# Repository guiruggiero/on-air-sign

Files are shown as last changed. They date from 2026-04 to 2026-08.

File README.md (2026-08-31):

# On Air sign

Automated "On Air" sign using a Raspberry Pi Pico 2 W — shows your meeting and webcam status:
- No meeting → OFF ⚫
- Meeting, camera off → YELLOW 🟡
- Meeting, camera on → RED 🔴

Works with Zoom, Google Meet, Slack Huddle, Amazon Chime, and Microsoft Teams. Only activates when connected to your home WiFi.

## Setup

### Pico
Wire the WS2812 NeoPixel ring data line to **GP4**.

Print and assemble the enclosures from `enclosures/` — a snap-fit box for the NeoPixel ring and a case for the Pico 2 W. See [`enclosures/README.md`](enclosures/README.md) for print settings.

The Pico firmware comes in two implementations — pick the one matching your host monitor (see below).

#### Pico (push variant, pairs with the Windows host monitor)
Upload `pico-push/main.py` and `pico-push/dashboard.html` to the Pico 2 W using Thonny. Create `pico-push/secrets.py` on the device:
```python
SSID = "<wifi_name>"
PASSWORD = "<wifi_password>"
WEBREPL_PW = "<webrepl_password>"
```
Assign the Pico a static IP via a DHCP reservation on your router so the hardcoded IP in `host-win/monitor.js` never changes. The Pico runs a local HTTP server and the host pushes state to it directly, so both must be on the same LAN.

Optionally, upload `pico-push/onairsign.html` to your personal website for easy access to the dashboard without remembering the IP.

#### Pico (pull variant, pairs with the macOS host monitor)
Upload `pico-pull/main.py` to the Pico 2 W using Thonny. Create a feed named `on-air-sign` on [Adafruit IO](https://io.adafruit.com), then create `pico-pull/secrets.py` on the device:
```python
SSID = "<wifi_name>"
PASSWORD = "<wifi_password>"
WEBREPL_PW = "<webrepl_password>"
AIO_USERNAME = "<adafruit_io_username>"
AIO_KEY = "<adafruit_io_key>"
```
The Pico polls this feed over HTTPS and drives the sign from its value (`off`/`yellow`/`red`) — no LAN adjacency with the host required, and no inbound connections accepted. `host-mac` writing to the feed automatically is still in progress (see [host-mac/CLAUDE.md](host-mac/CLAUDE.md)); until then you can set the feed's value manually from the Adafruit IO dashboard to test the Pico side.

### Host monitor (Windows)
Requires Node.js and PowerShell 7 (`pwsh`). Set the HOME_SSID environment variable:
```powershell
[System.Environment]::SetEnvironmentVariable("HOME_SSID", "<your_ssid>", "User")
```
Then run:
```powershell
node host-win/monitor.js
```

#### Autostart
To run the monitor automatically on login via Windows Task Scheduler:
1. Copy `host-win/launch-monitor.vbs.example` → `host-win/launch-monitor.vbs` and fill in your Node.js path and repo path
2. Copy `host-win/On Air sign monitor.xml.example` → `host-win/On Air sign monitor.xml` and replace `DOMAIN\username`, `DATE`, and the paths in `<Actions>`
3. Open Task Scheduler → Action → Import Task, and select `host-win\On Air sign monitor.xml`

### Host monitor (macOS)
Requires Node.js and the Xcode Command Line Tools (for `swiftc` — usually already installed). Build the native probe once, then run:
```bash
cd host-mac
./build.sh
export HOME_SSID="<your_ssid>"
node monitor.js
```
On first run, grant these in System Settings → Privacy & Security: **Screen Recording** (so the probe can read meeting-app window titles — without it no meeting is detected) and **Location Services** for your terminal/Node (required by macOS to read the WiFi network name). Camera state needs no permission. See [host-mac/CLAUDE.md](host-mac/CLAUDE.md) for details.

#### Autostart
To run the monitor automatically on login via launchd:
1. Copy `host-mac/com.onairsign.monitor.plist.example` → `host-mac/com.onairsign.monitor.plist` and fill in your Node.js path, repo path, and HOME_SSID
2. Symlink or copy it into `~/Library/LaunchAgents/` and load it:
   ```bash
   cp "host-mac/com.onairsign.monitor.plist" ~/Library/LaunchAgents/
   launchctl load ~/Library/LaunchAgents/com.onairsign.monitor.plist
   ```

---

#### 📄 License
This project is licensed under the [MIT License](LICENSE). Attribution is required.

#### ⚠️ Disclaimer
This software is provided "as is" without any warranties. Use at your own risk. The author is not responsible for any consequences of using this software.

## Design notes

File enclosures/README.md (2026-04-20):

# Enclosures

3D print files for the project. No supports needed in any of the files.

For the most up-to-date designs, see Tinkercad profile [TinkerGui](https://www.tinkercad.com/users/7svhW7zioAZ).

## Pico case

Files: `Raspberry Pi Pico 2 W case - bottom.stl`, `Raspberry Pi Pico 2 W case - top.stl`

Based on maximilliampere's [slim modular Pico case](https://www.printables.com/model/61680-slim-modular-raspberry-pi-pico-case).

Print settings:
- Layer height: 0.2 mm
- Infill: 20%

## Sign box

Files: `On Air box - base.stl`, `On Air box - lid.stl`, `On Air box - letters.stl`

Houses the 12-LED WS2812 NeoPixel ring. Custom designs.

Print settings (base):
- Layer height: 0.2 mm
- Infill: 15%

Print settings (lid and letters):
- Layer height: 0.3 mm
- Infill: 15%

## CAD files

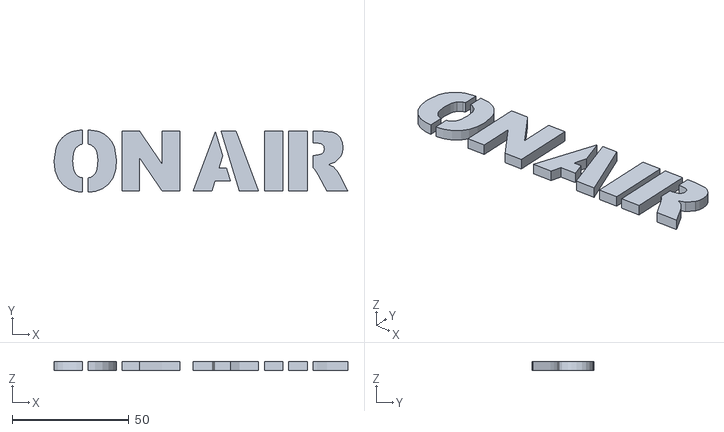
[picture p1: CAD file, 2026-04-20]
enclosures/On Air box - letters.stl
125.9 x 26.7 x 4.00

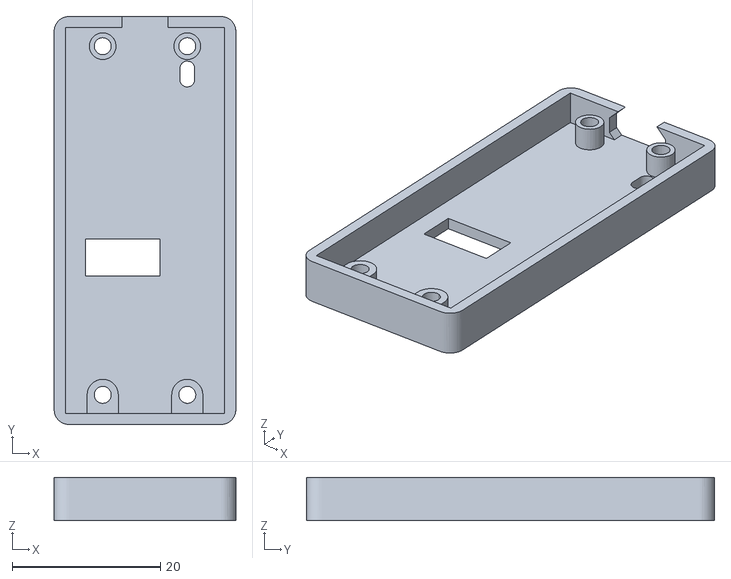
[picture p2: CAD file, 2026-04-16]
enclosures/Raspberry Pi Pico 2 W case - top.stl
24.5 x 55.0 x 5.80

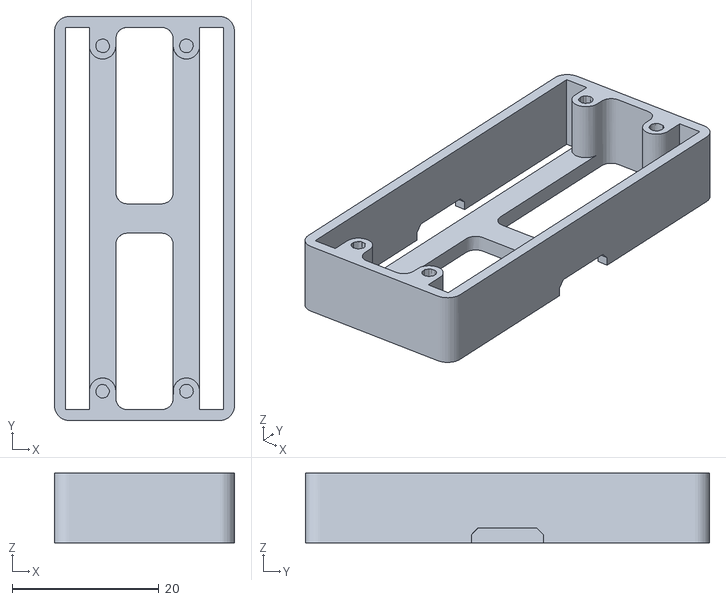
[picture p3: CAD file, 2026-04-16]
enclosures/Raspberry Pi Pico 2 W case - bottom.stl
24.5 x 55.0 x 9.50

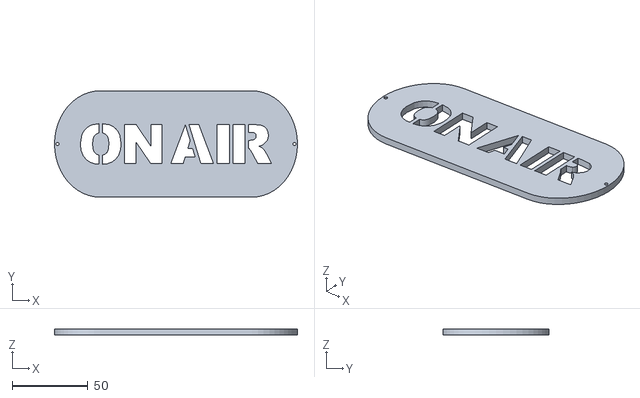
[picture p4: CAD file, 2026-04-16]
enclosures/On Air box - lid.stl
160.0 x 70.0 x 4.00

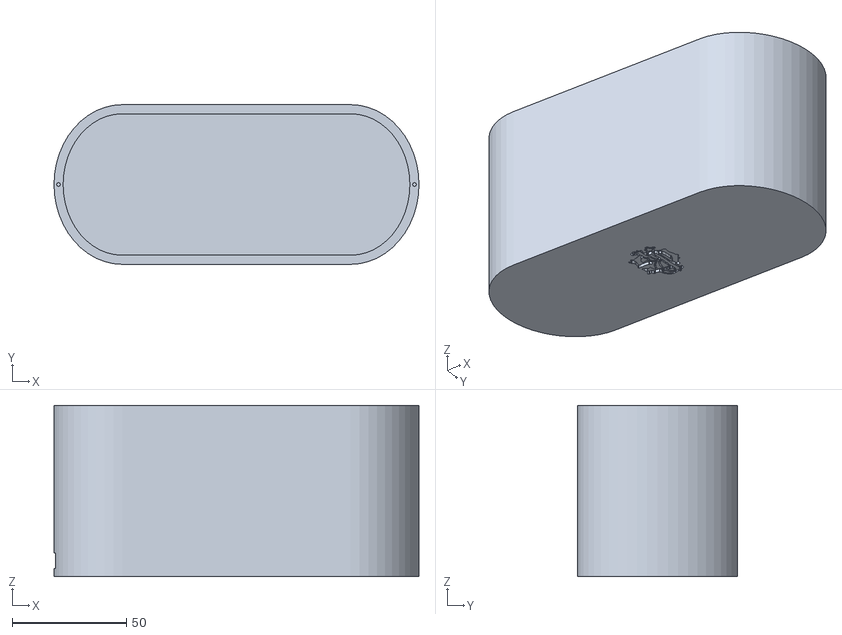
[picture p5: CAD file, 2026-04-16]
enclosures/On Air box - base.stl
160.0 x 70.0 x 75.0

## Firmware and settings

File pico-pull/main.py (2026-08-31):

# Imports
import secrets
import time
import os
import rp2
import machine
import array
import network
import socket
import ssl
import json
import gc

# Initializations
SSID = secrets.SSID
PASSWORD = secrets.PASSWORD
WEBREPL_PW = secrets.WEBREPL_PW
AIO_USERNAME = secrets.AIO_USERNAME
AIO_KEY = secrets.AIO_KEY

# Adafruit IO feed ("red", "yellow", or "off")
AIO_HOST = "io.adafruit.com"
AIO_FEED = "on-air-sign"
AIO_PATH = f"/api/v2/{AIO_USERNAME}/feeds/{AIO_FEED}/data/last"
POLL_INTERVAL_MS = 3_000 # 3s
WATCHDOG_TIMEOUT_MS = 300_000 # 5m; turn off if feed unreachable or stale info
UNIX_EPOCH_OFFSET = 946_684_800 # seconds between Adafruit IO's created_epoch and MicroPython's time.time() epoch

# Persistent logging to flash
LOG_PATH = "logs.log"
ERR_PATH = "errors.log"
LOG_MAX_BYTES = 20_000

def trim_log(path):
    try:
        size = os.stat(path)[6]
        if size > LOG_MAX_BYTES:
            with open(path, "r") as f:
                f.seek(size // 2)
                f.readline() # Discard the partial line at the seek point
                keep = f.read()
            with open(path, "w") as f:
                f.write(keep)
    except OSError:
        pass

def log(msg):
    t = time.localtime(time.time() - 8 * 3600)
    line = f"[{t[1]:02}-{t[2]:02} {t[3]:02}:{t[4]:02}:{t[5]:02}] {msg}"
    print(line)
    try:
        trim_log(LOG_PATH)
        with open(LOG_PATH, "a") as f:
            f.write(line + "\n")
    except Exception:
        pass
    return line

def log_error(msg):
    line = log(msg)
    try:
        trim_log(ERR_PATH)
        with open(ERR_PATH, "a") as f:
            f.write(line + "\n")
    except Exception:
        pass

# GRB values (brightness-adjusted, GRB byte order for WS2812)
BRIGHTNESS = 0.4  # 0.0 (off) to 1.0 (full brightness)
def _to_grb(r, g, b):
    return (int(g * BRIGHTNESS) << 16) | (int(r * BRIGHTNESS) << 8) | int(b * BRIGHTNESS)
GRB_OFF    = _to_grb(0, 0, 0)
GRB_YELLOW = _to_grb(204, 153, 0)
GRB_RED    = _to_grb(255, 0, 0)
GRB_GREEN  = _to_grb(0, 255, 0)

STATE_MAP = {
    "off": GRB_OFF,
    "o": GRB_OFF,
    "yellow": GRB_YELLOW,
    "y": GRB_YELLOW,
    "red": GRB_RED,
    "r": GRB_RED,
}

# PIO NeoPixel driver for Raspberry Pi Pico 2
@rp2.asm_pio(sideset_init = rp2.PIO.OUT_LOW, out_shiftdir = rp2.PIO.SHIFT_LEFT, autopull = True, pull_thresh = 24)
def ws2812():
    T1, T2, T3 = 2, 5, 3
    wrap_target()
    label("bitloop")
    out(x, 1).side(0)[T3 - 1]
    jmp(not_x, "do_zero").side(1)[T1 - 1]
    jmp("bitloop").side(1)[T2 - 1]
    label("do_zero")
    nop().side(0)[T2 - 1]
    wrap()

# Initialize StateMachine on the data pin
DATA_PIN = 4
NUM_LEDS = 12
sm = rp2.StateMachine(0, ws2812, freq = 8_000_000, sideset_base = machine.Pin(DATA_PIN))
sm.active(1)
pixel_data = array.array("I", [0] * NUM_LEDS) # Internal buffer

# Change color of LEDs
def set_sign(grb):
    for i in range(NUM_LEDS):
        pixel_data[i] = grb
    sm.put(pixel_data, 8) # Send to PIO
    time.sleep_ms(10) # Brief settle time to ensure the PIO FIFO buffer is cleared

# Sync local clock to NTP time
def sync_ntp():
    try:
        import ntptime
        ntptime.settime()
        log("NTP time synced")
    except Exception:
        log_error("NTP sync failed")

# Connect to WiFi
wlan = network.WLAN(network.STA_IF)
def connect_wifi(initial=False):
    wlan.active(True)
    if not wlan.isconnected():
        wlan.connect(SSID, PASSWORD)
        log("Connecting to WiFi...")
        on = False
        for _ in range(40): # 20s timeout
            if wlan.isconnected():
                break
            on = not on
            set_sign(GRB_GREEN if on else GRB_OFF) # Blink green while connecting
            time.sleep(0.5)
        else:
            set_sign(GRB_OFF)
            log_error("WiFi connection failed, resetting...")
            machine.reset()

    ip = wlan.ifconfig()[0]
    log(f"Connected! IP: {ip}")
    sync_ntp()
    if initial:
        set_sign(GRB_GREEN) # Solid green on first boot
        time.sleep(3)
        set_sign(GRB_OFF)
    return ip

ip = connect_wifi(initial=True)

# WebREPL for updating files over WiFi
try:
    import webrepl
    webrepl.start(password = WEBREPL_PW) # Update via WiFi on http://micropython.org/webrepl with ws://<PICO_IP>:8266
except Exception:
    log_error("WebREPL not available")

# Dechunk an HTTP/1.1 chunked-transfer-encoded body
def dechunk(data):
    out = b""
    while data:
        size_end = data.index(b"\r\n")
        size = int(data[:size_end], 16)
        if size == 0:
            break
        chunk_start = size_end + 2
        out += data[chunk_start:chunk_start + size]
        data = data[chunk_start + size + 2:] # Skip the chunk's trailing \r\n
    return out

# Minimal HTTPS GET; reads until the server closes the connection
def https_get(host, path, headers):
    addr = socket.getaddrinfo(host, 443)[0][-1]
    raw = socket.socket()
    raw.settimeout(8.0)
    raw.connect(addr)
    s = ssl.wrap_socket(raw, server_hostname=host)
    try:
        req_lines = [f"GET {path} HTTP/1.1", f"Host: {host}", "Connection: close"]
        for k, v in headers.items():
            req_lines.append(f"{k}: {v}")
        req_lines.append("\r\n")
        s.write("\r\n".join(req_lines).encode())

        data = b""
        while True:
            chunk = s.read(1024)
            if not chunk:
                break
            data += chunk
    finally:
        s.close()

    header_end = data.index(b"\r\n\r\n")
    header_text = data[:header_end].decode()
    body = data[header_end + 4:]

    status_code = int(header_text.split("\r\n", 1)[0].split(" ")[1])
    resp_headers = {}
    for line in header_text.split("\r\n")[1:]:
        if ":" in line:
            k, v = line.split(":", 1)
            resp_headers[k.strip().lower()] = v.strip()

    if resp_headers.get("transfer-encoding") == "chunked":
        body = dechunk(body)

    return status_code, body

# Fetch current state and last update time from Adafruit IO
def fetch_state():
    status, body = https_get(AIO_HOST, AIO_PATH, {"X-AIO-Key": AIO_KEY})
    if status != 200:
        raise Exception(f"Adafruit IO returned HTTP {status}")
    data = json.loads(body)
    return data["value"], int(data["created_epoch"])

log(f"Polling Adafruit IO every {POLL_INTERVAL_MS // 1000}s")
last_fresh_time = time.ticks_ms()
last_ntp_sync = time.ticks_ms()
NTP_SYNC_INTERVAL = 24 * 60 * 60 * 1000 # 24 hours
STALE_MSG_LOGGED = False

while True:
    gc.collect() # Periodically clean up memory

    # Periodic NTP re-sync to correct clock drift
    if time.ticks_diff(time.ticks_ms(), last_ntp_sync) > NTP_SYNC_INTERVAL:
        sync_ntp()
        last_ntp_sync = time.ticks_ms()

    try:
        if not wlan.isconnected():
            log_error("WiFi lost, reconnecting...")
            connect_wifi()

        value, created_epoch = fetch_state()
        age_s = (time.time() + UNIX_EPOCH_OFFSET) - created_epoch

        if age_s <= WATCHDOG_TIMEOUT_MS // 1000:
            last_fresh_time = time.ticks_ms()
            STALE_MSG_LOGGED = False

            grb = STATE_MAP.get(value)
            if grb is None:
                log_error(f"Unknown feed value: {value}")
            elif grb != pixel_data[0]:
                log(f"State changed: {value}")
                set_sign(grb)
        elif not STALE_MSG_LOGGED:
            log(f"Feed value is stale ({age_s}s old), ignoring until it updates")
            STALE_MSG_LOGGED = True

    except Exception as e:
        log_error(f"Poll failed: {e}")

    # Watchdog: turn off sign if feed unreachable or stale info
    if pixel_data[0] != GRB_OFF and time.ticks_diff(time.ticks_ms(), last_fresh_time) > WATCHDOG_TIMEOUT_MS:
        log("No fresh feed value in 5 minutes, turning off sign")
        set_sign(GRB_OFF)

    time.sleep_ms(POLL_INTERVAL_MS)

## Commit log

2026-03-16 Added main from Claude with Gemini modifications and official example from Raspberry Pi
2026-03-16 Increased resiliency to network hiccups and memory issues
    [main.py]
2026-03-16 Improved stability and memory optimizations for long-running server
    [main.py]
2026-03-16 Updated camera check with multiple paths
2026-03-17 Simplified meeting check powershell command, improved timeouts, added graceful shutdown and heartbeat
2026-03-17 Changed PowerShell commands to encoded Base64 strings
2026-03-17 Enhanced PowerShell commands for silent execution
2026-03-17 Moved to PowerShell 7 for speed
2026-03-28 Added local manual control from any device, updates over WiFi with WebREPL
2026-03-28 Fixed webpage and serving it correctly
    [main.py]
2026-03-28 Fixed stale socket after WiFi reconnect
    [main.py]
2026-03-28 Guarded WebREPL import/start so missing setup doesn't crash on boot
    [main.py]
2026-03-28 Guarded mDNS setup so unsupported firmware doesn't crash on boot
    [main.py]
2026-03-28 Added 20s timeout to WiFi connection, reset Pico on failure
    [main.py]
2026-03-28 Removed local manual control from any device
2026-03-30 Refactor main.py: consolidate routes, precompute GRB colors, fix bare excepts, drop neopixel_ring.py
    [main.py]
2026-04-01 Organize repo into pico/ and host/ folders
2026-04-01 Feat: add resilience with Pico watchdog timeout, monitor heartbeat, socket recovery
2026-04-01 Extract inline PowerShell to dedicated script loaded from file
2026-04-02 Feat: persistent file logging with auto-rotation to both Pico and monitor, AGENTS.md hardlink to CLAUDE.md
2026-04-03 Fix: log trimming and timestamps include date, CORS headers on all responses, dashboard uses onairsign.local with error feedback, mDNS malformed packet guard
    [main.py]
2026-04-03 Improve resource usage and fix minor bugs across Pico and host
    [main.py]
2026-04-04 Fix: mDNS EADDRINUSE on re-run by closing existing socket before rebin
2026-04-07 Add Pico memory and uptime stats to dashboard
2026-04-07 Refactor: Pico logging to match host
2026-04-07 Hardcode Pico IP, remove env var and dashboard prompt
2026-04-07 Add /logs and /errors endpoints to Pico and link them in dashboard
    [main.py]
2026-04-08 Address SonarQube concerns
2026-04-16 Add 3D printing enclosure designs
    [On Air box - bottom.stl, On Air box - top.stl, Raspberry Pi Pico 2 W case - bottom.stl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]
2026-04-16 Add enclosures folder README
2026-04-20 Change file names, add letters and print settings
    [On Air box - base.stl, On Air box - letters.stl, On Air box - lid.stl]
2026-08-07 Docs: add SonarQube Cloud project key
2026-08-31 Fix: use node: import prefixes, [[ ]] in poll.sh, remove duplicate <html> tag, fix dead f-string, and improve RED button contrast
    [main.py]
2026-09-14 Docs: note admin dashboard integration pending on Pico firmware work
2026-10-10 Fix: raise RuntimeError instead of generic Exception in pico-pull
2026-11-02 Refact: reorganize repo into win/{host,pico} and mac/{host,pico}
2026-11-02 Refact: simplify mac host with router-MAC home check, native probe checks, and per-app meeting rules
2026-11-02 Refact: drop alive log, shorten probe timeout to 2s, and strip trailing newlines
2026-11-02 Feat: Pico receives the feed over MQTT; Mac polls every 3s
2026-11-02 Feat: Pico heartbeat to the pico feed and manual hold (red:60)
2026-11-02 Feat: Pico heartbeat reports used memory
2026-11-02 Fix: SonarQube findings in mac host monitor (complexity, unawaited promises, log injection)
2026-11-02 Docs: admin card live, buttons left on roadmap
